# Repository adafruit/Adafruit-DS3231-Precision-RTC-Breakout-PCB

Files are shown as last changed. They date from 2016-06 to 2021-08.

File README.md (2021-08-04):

## Adafruit DS3231 Precision RTC Breakout PCB
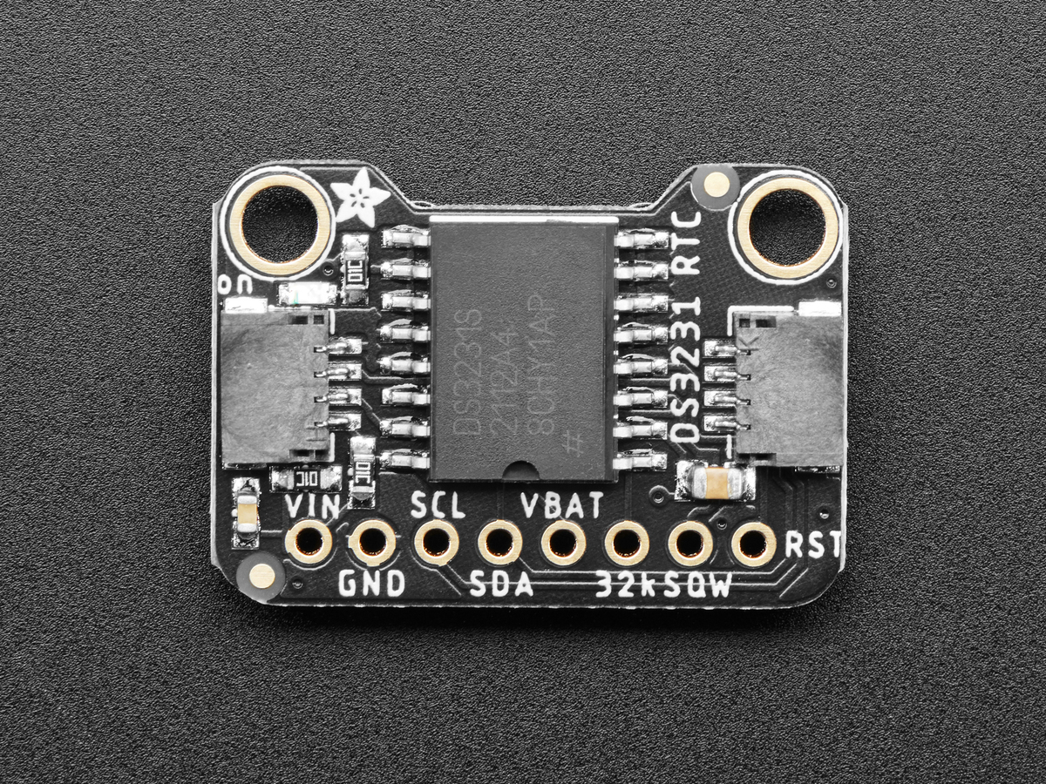
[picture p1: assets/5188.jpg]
<a href="http://www.adafruit.com/products/5188"><br/>
Click here to purchase one from the Adafruit shop</a><br/>
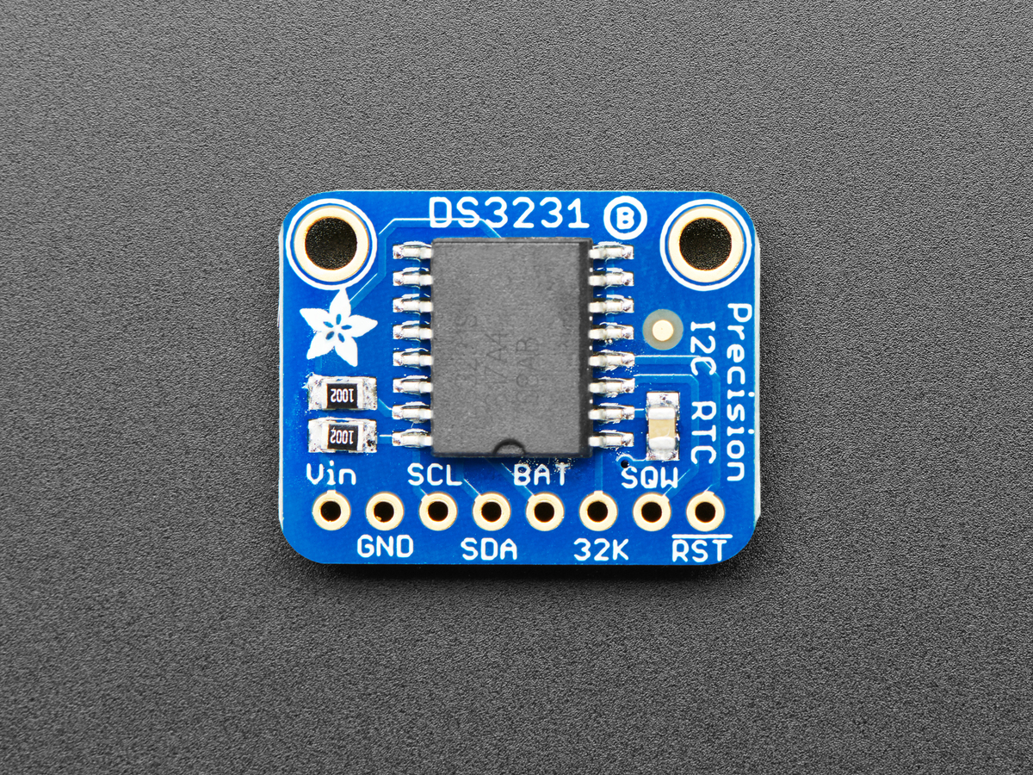
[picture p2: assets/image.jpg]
<a href="http://www.adafruit.com/products/3013"><br/>
Click here to purchase one from the Adafruit shop</a>

The datasheet for the DS3231 explains that this part is an "Extremely Accurate I²C-Integrated RTC/TCXO/Crystal". And, hey, it does exactly what it says on the tin! This Real Time Clock (RTC) is the most precise you can get in a small, low power package.

Most RTCs use an external 32kHz timing crystal that is used to keep time with low current draw. And that's all well and good, but those crystals have slight drift, particularly when the temperature changes (the temperature changes the oscillation frequency very very very slightly but it does add up!) This RTC is in a beefy package because the crystal is inside the chip! And right next to the integrated crystal is a temperature sensor. That sensor compensates for the frequency changes by adding or removing clock ticks so that the timekeeping stays on schedule.

This is the finest RTC you can get, and now we have it in a compact, breadboard-friendly breakout. With a coin cell plugged into the back, you can get years of precision timekeeping, even when main power is lost. Great for datalogging and clocks, or anything where you need to really know the time.

PCB files for the Adafruit DS3231 Precision RTC Breakout. The format is EagleCAD schematic and board layout
- https://www.adafruit.com/products/3013

### License

Adafruit invests time and resources providing this open source design, please support Adafruit and open-source hardware by purchasing products from [Adafruit](https://www.adafruit.com)!

All text above must be included in any redistribution

Designed by Limor Fried/Ladyada for Adafruit Industries.
Creative Commons Attribution/Share-Alike, all text above must be included in any redistribution. 
See license.txt for additional information.

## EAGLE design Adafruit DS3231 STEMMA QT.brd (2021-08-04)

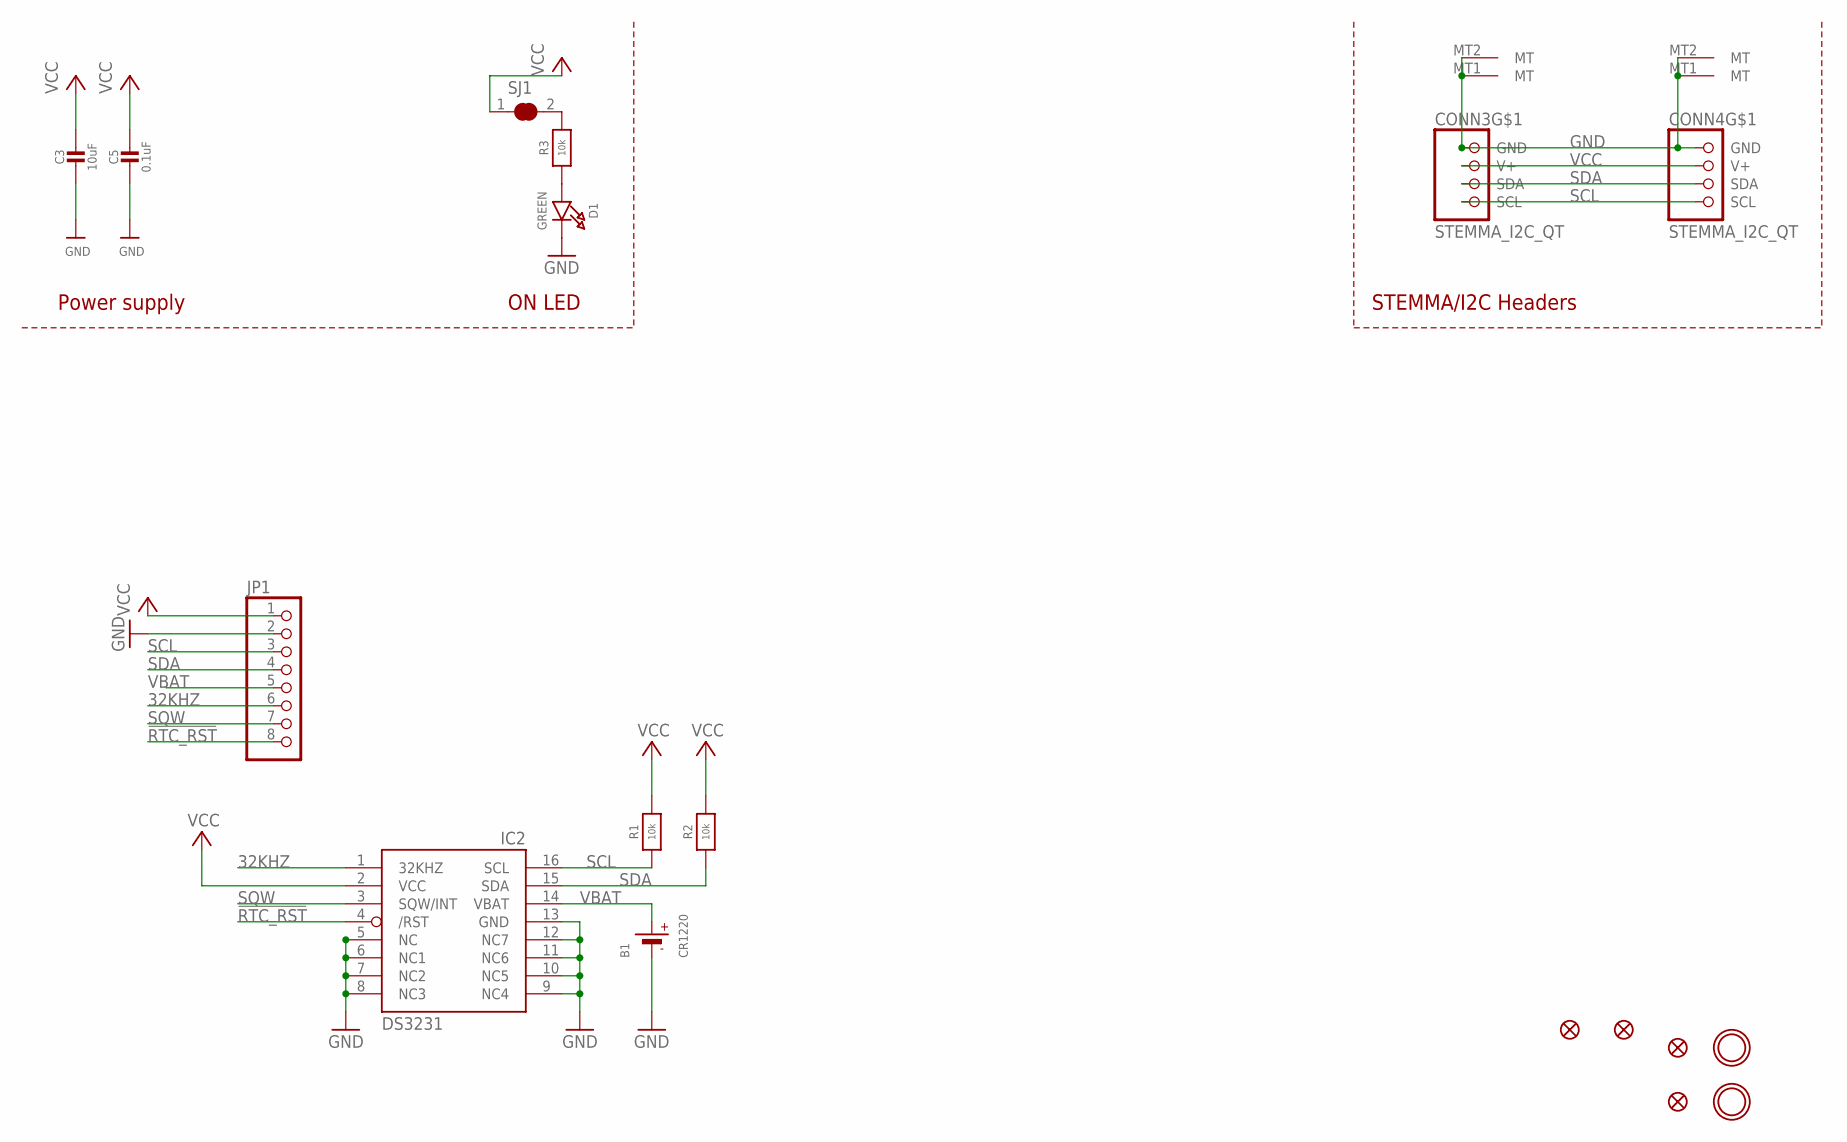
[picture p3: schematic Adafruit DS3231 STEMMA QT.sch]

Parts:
B1: CR1220
C3: 10uF; 0805-NO
C5: 0.1uF; 0603-NO
CONN3, CONN4: STEMMA_I2C_QT; JST_SH4
D1: GREEN; CHIPLED_0603_NOOUTLINE
FID1, FID2, FID3, FID4: FIDUCIAL_1MM
IC2: DS3231/SO; SO16W
JP1: HEADER-1X870MIL; 1X08_ROUND_70
R1, R2, R3: 10k; 0603-NO
SJ1: SOLDERJUMPER_CLOSED; SOLDERJUMPER_CLOSEDWIRE
U$9, U$17: MOUNTINGHOLE3.0THIN; MOUNTINGHOLE_3.0_PLATEDTHIN

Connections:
32KHZ: IC2.1 (32KHZ), JP1.6
!RTC_RST: IC2.4 (/RST), JP1.8
GND: B1.-, C3.2, C5.2, CONN3.1 (GND), CONN3.MT1 (MT), CONN3.MT2 (MT), CONN4.1 (GND), CONN4.MT1 (MT), CONN4.MT2 (MT), D1.C, IC2.5 (NC), IC2.6 (NC1), IC2.7 (NC2), IC2.8 (NC3), IC2.9 (NC4), IC2.10 (NC5), IC2.11 (NC6), IC2.12 (NC7), IC2.13 (GND), JP1.2
unnamed: R3.2, SJ1.2
unnamed: D1.A, R3.1
SCL: CONN3.4 (SCL), CONN4.4 (SCL), IC2.16 (SCL), JP1.3, R1.1
SDA: CONN3.3 (SDA), CONN4.3 (SDA), IC2.15 (SDA), JP1.4, R2.1
SQW: IC2.3 (SQW/INT), JP1.7
VBAT: B1.+$1 (+), B1.+$2 (+), IC2.14 (VBAT), JP1.5
VCC: C3.1, C5.1, CONN3.2 (V+), CONN4.2 (V+), IC2.2 (VCC), JP1.1, R1.2, R2.2, SJ1.1

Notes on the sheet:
STEMMA/I2C Headers
ON LED
Power supply

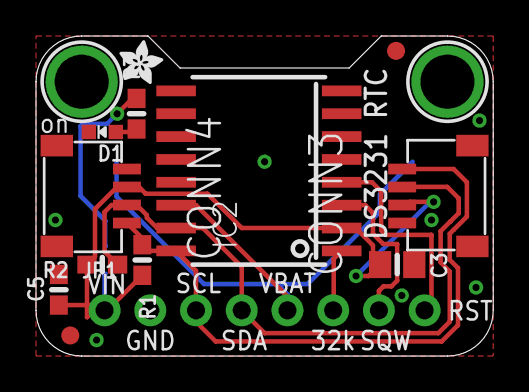
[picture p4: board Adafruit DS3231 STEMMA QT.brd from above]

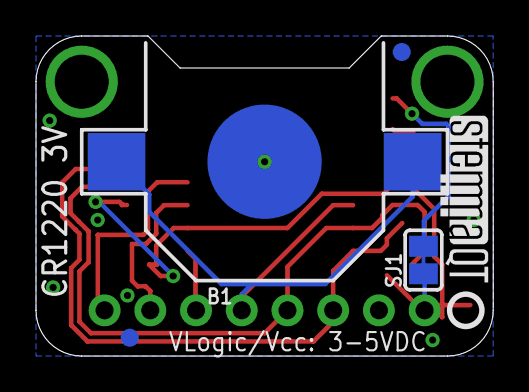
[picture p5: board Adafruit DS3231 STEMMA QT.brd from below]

Board: 2 copper layers, 25.4 x 17.8 mm, 21 parts (6 on the bottom side), 10 nets.

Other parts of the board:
U$1: ADAFRUIT_2.5MM
U$25: PCBFEAT-REV-040
U$31: STEMMAQT

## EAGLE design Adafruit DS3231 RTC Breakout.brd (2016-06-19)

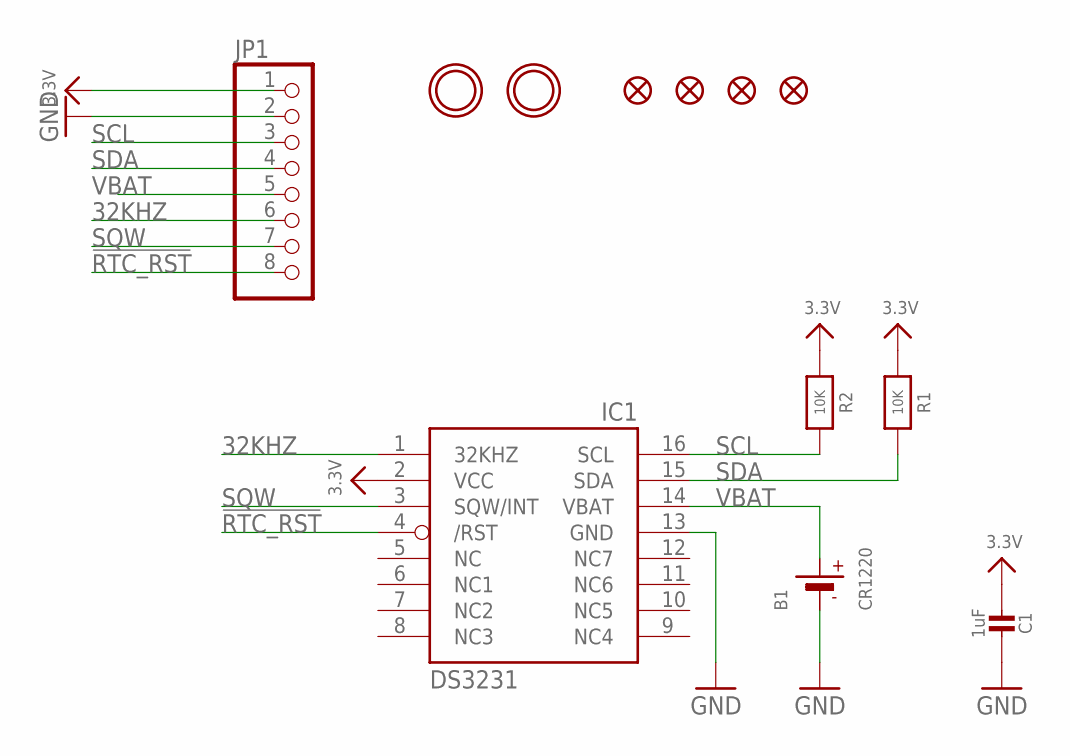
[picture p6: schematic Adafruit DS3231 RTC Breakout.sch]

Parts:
B1: CR1220
C1: 1uF; 0805-NO
FID1, FID2, FID3, FID4: FIDUCIAL""; FIDUCIAL_1MM
IC1: DS3231/SO; SO16W
JP1: HEADER-1X870MIL; 1X08_ROUND_70
R1, R2: 10K; 0805-NO
U$6, U$7: MOUNTINGHOLE2.5; MOUNTINGHOLE_2.5_PLATED

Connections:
3.3V: C1.2, IC1.2 (VCC), JP1.1, R1.1, R2.1
32KHZ: IC1.1 (32KHZ), JP1.6
!RTC_RST: IC1.4 (/RST), JP1.8
GND: B1.-, C1.1, IC1.13 (GND), JP1.2
SCL: IC1.16 (SCL), JP1.3, R2.2
SDA: IC1.15 (SDA), JP1.4, R1.2
SQW: IC1.3 (SQW/INT), JP1.7
VBAT: B1.+$1 (+), IC1.14 (VBAT), JP1.5

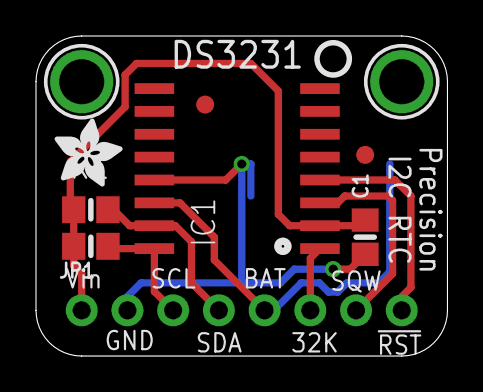
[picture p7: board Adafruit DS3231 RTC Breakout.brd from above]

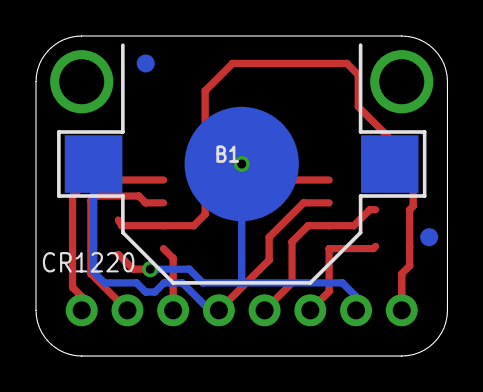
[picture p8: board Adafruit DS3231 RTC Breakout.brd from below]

Board: 2 copper layers, 22.9 x 17.8 mm, 14 parts (3 on the bottom side), 8 nets.

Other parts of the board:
U$8: ADAFRUIT_3.5MM
U$9: PCBFEAT-REV-040

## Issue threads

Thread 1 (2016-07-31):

NC pins not connected to ground

madvoid, 2016-07-31:
On page 9 of the most recent [datasheet](https://datasheets.maximintegrated.com/en/ds/DS3231.pdf) for the DS3231, it is stated that the all the No Connection (NC) pins must be connected to ground. However, it does not appear that the pins are connected this way on the breakout board. This is probably not a big deal as all the boards I've tried work well, but I just thought I'd put it out there. Thanks!

\- NG

ladyada, 2016-08-01:
heh - thats a very exotic use of the phrase "No connection" :D

madvoid, 2016-08-01:
Ha, very true! I'm going to mark this as closed, thanks again.

ladyada, 2016-08-01:
kthx - will update next time we do a PCB rev - no ETA at this time!

ladyada, 2018-12-04:
oops yeah we forgot to revise, next PCB run for sure :)

Closed 2016-08-01.

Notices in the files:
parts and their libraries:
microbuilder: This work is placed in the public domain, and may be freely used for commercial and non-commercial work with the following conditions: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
